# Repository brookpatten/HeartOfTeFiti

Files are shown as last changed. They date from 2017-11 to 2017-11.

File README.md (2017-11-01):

# HeartOfTeFiti
A 3d Printed Amulet with Neopixels controlled by an Arduino, Synchronized with other via NRF24 Radio.

When the button is pushed the arduino chooses a random light pattern and displays it.  While displaying it broadcasts each pixel value using the nrf24 radio to any nearby units as well.  Nearby units will receive the pixel instructions and replicate the pattern.  When the pattern ends there is a 5 second interval before another pattern can be begun (by any which participated in the previous pattern).

Components
* Shell/Cover (3d printed, models included)
* Arduino Pro Mini 3.3v
* NRF24001+ Transciever
* 5x Addressable LED
* 2x 10uf Capacitors (Optional but recommended)
* 2x 470 ohm resistors (Optional but recommended)
* wire, Recommend 30awg solid
* momentary button switch
* 3.7v 370mah li-poly Battery
* 2x M3 x 10mm Hex Head Bolt

For Assembly
 * Solder
 * Hot Glue (Optional)
 * Necklace
 
Demo

Front

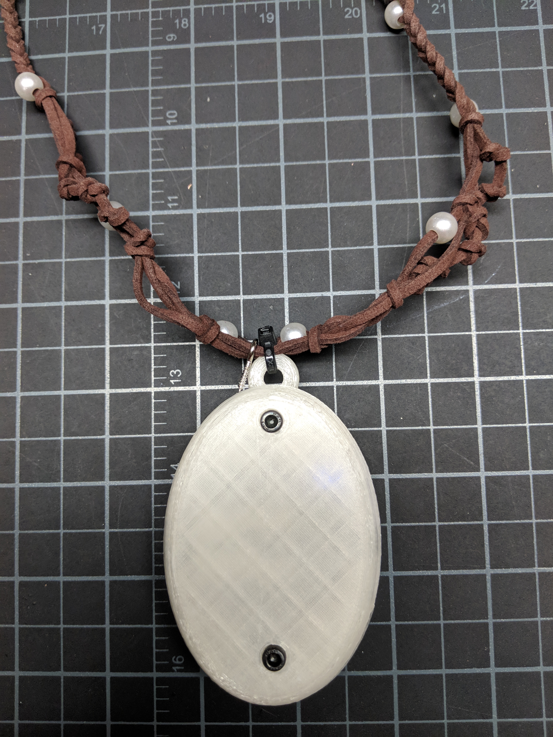
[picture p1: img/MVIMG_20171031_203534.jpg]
Back


Apart

Internals

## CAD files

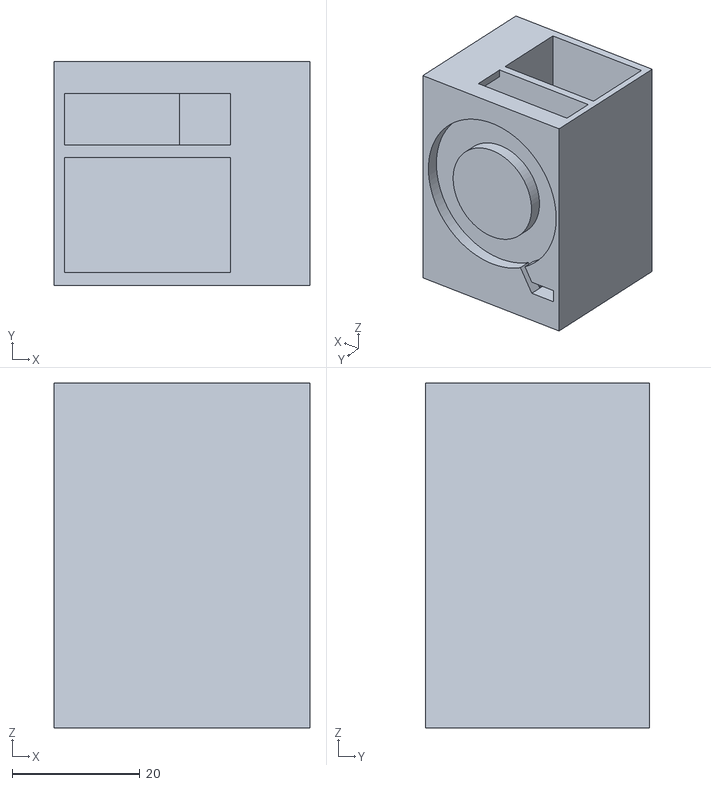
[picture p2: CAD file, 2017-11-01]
Meshes/Pumpkin-Candle.stl
40.0 x 35.0 x 54.0

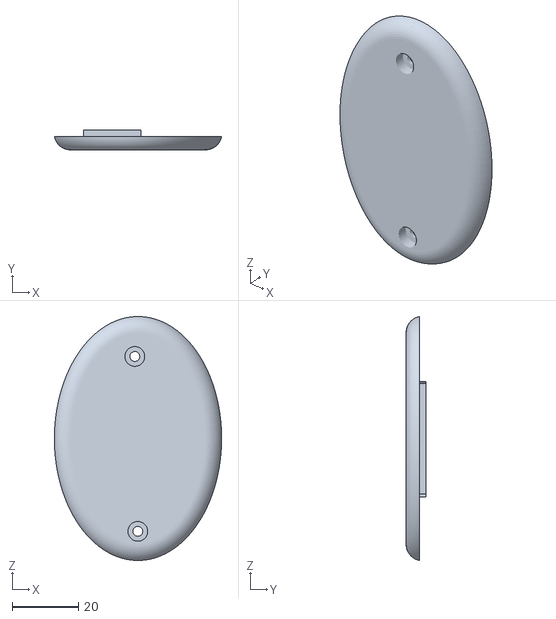
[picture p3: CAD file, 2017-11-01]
Meshes/Cover.stl
50.7 x 6.00 x 73.9

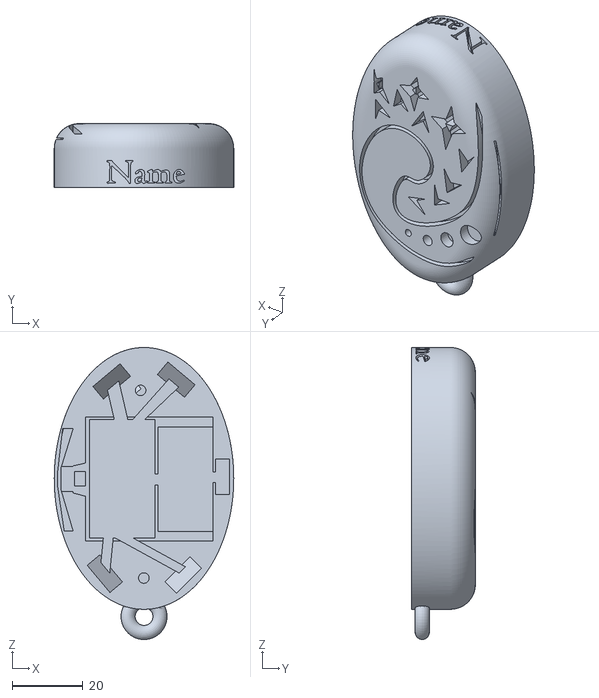
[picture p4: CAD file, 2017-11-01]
Meshes/Heart.stl
50.7 x 18.0 x 82.4

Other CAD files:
Fusion360Models/Heart.f3d
Fusion360Models/Pumpkin-Candle.f3d

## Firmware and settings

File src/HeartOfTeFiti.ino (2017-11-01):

#include <Adafruit_NeoPixel.h>
#include <SPI.h>
#include "RF24.h"
#include <printf.h>

const int pixelCount = 5;
// Parameter 1 = number of pixels in strip
// Parameter 2 = pin number (most are valid)
// Parameter 3 = pixel type flags, add together as needed:
//   NEO_KHZ800  800 KHz bitstream (most NeoPixel products w/WS2812 LEDs)
//   NEO_KHZ400  400 KHz (classic 'v1' (not v2) FLORA pixels, WS2811 drivers)
//   NEO_GRB     Pixels are wired for GRB bitstream (most NeoPixel products)
//   NEO_RGB     Pixels are wired for RGB bitstream (v1 FLORA pixels, not v2)
Adafruit_NeoPixel strip = Adafruit_NeoPixel(pixelCount, pixelCount, NEO_GRB + NEO_KHZ800);

//nrf24 radio
RF24 radio(10, 9);
byte addresses[][6] = {"1Node", "2Node"};

//millis of timestamp of last data received
volatile unsigned long lastReceive = 0;
//millis of timestamp of last data sent
volatile unsigned long lastSend = 0;
//default delay used in patterns
const int defaultDelay = 10;
const unsigned long idleTimeout = 5000;

volatile unsigned long dividerTicks = 0;
volatile unsigned long idleTicks = 0;

//this setting puts it in "pumpkin mode" so that a special version of the device 
//can be used as the light for a jackolantern and will react to the amulets too
const bool isPumpkin = false;

//structure for sending pixel commands over radio
typedef struct {
  byte index;
  byte r;
  byte g;
  byte b;
  bool show;
}
pixel;

//structure for buffering rgb combos for patterns
typedef struct {
  byte r;
  byte g;
  byte b;
}
rgb;

void setup() {
  //Serial.begin(9600);

  //pixel setup
  strip.begin();
  strip.setBrightness(64);
  strip.show(); // Initialize all pixels to 'off'

  //setup the button
  pinMode(3, INPUT);
  attachInterrupt(digitalPinToInterrupt(3), button, RISING);

  //radio setup
  radio.begin();
  radio.setDataRate(RF24_250KBPS);
  radio.setPALevel(RF24_PA_LOW);
  radio.openWritingPipe(addresses[0]);
  radio.openReadingPipe(1, addresses[0]);
  radio.setAutoAck( false ) ;
  radio.startListening();

  int channel = radio.getChannel();
  //Serial.print("Channel ");
  //Serial.println(channel);
  //printf_begin();
  //radio.printDetails();

  //if it's a pumpking show yellow
  if(isPumpkin){
    for(int i=0;i<pixelCount;i++){
      strip.setPixelColor(i, 255, 255, 0);
    }
    strip.show();
  }

  //Serial.println("Setup Complete");
  //Serial.flush();
}

//invoked when the button is pushed
void button() {
  unsigned long now = millis();

  //don't let the user interrupt a pattern in process
  if ((lastReceive == 0 || now - lastReceive > idleTimeout)
      && (lastSend == 0 || now - lastSend > idleTimeout))
  {
    randomPattern();
  }

  //if it's a pumpkin return to yello after the pattern
  if(isPumpkin){
    for(int i=0;i<pixelCount;i++){
      strip.setPixelColor(i, 255, 255, 0);
    }
    strip.show();
  }
}

//convenience method to set local and remote pixels to the same values
void setLocalAndRemotePixelColor(byte index, byte r, byte g, byte b, bool show) {
  strip.setPixelColor(index, r, g, b);
  setRemotePixelColor(index, r, g, b, show);
  if (show) {
    strip.show();
  }
}

//call at beginning of every pattern
void startPattern() {
  radio.stopListening();
  idleTicks = 0;
  dividerTicks = 0;
}

//call at end of every pattern
void endPattern() {
  clearPixels();
  idleTicks = 1;
  dividerTicks = 1;
  radio.startListening();
}

void clearPixels() {
  for (int p = 0; p < pixelCount; p++) {
    setLocalAndRemotePixelColor(p, 0, 0, 0, p == pixelCount - 1);
  }
}

//sends a pixel value to be set on listening devices
void setRemotePixelColor(byte index, byte r, byte g, byte b, bool show) {
  pixel p;
  p.index = index;
  p.r = r;
  p.g = g;
  p.b = b;
  p.show = show;

  radio.write( &p, sizeof(pixel) );

  lastSend = millis();
}

void loop() {
  if ( radio.available()) {
    pixel p;

    while (radio.available()) {
      radio.read( &p, sizeof(pixel) );
      lastReceive = millis();

      //it's possible the sender has more pixels than we do, make sure we're showing it somewhere
      strip.setPixelColor(p.index % pixelCount, p.r, p.g, p.b);
      
      if (p.show) {
        strip.show();
      }
      //reset the idle counter so that the idle pattern syncs up when this pattern is done
      idleTicks = 1;
      dividerTicks = 1;

      //if it's a pumpkin then return to yellow
      if(isPumpkin){
        if(p.r==0 && p.g==0 && p.b==0 && p.show){
          for(int i=0;i<pixelCount;i++){
            strip.setPixelColor(i, 255, 255, 0);
          }
          strip.show();
        }
      }
    }
  }
  //TODO: get this working.  Right now it seems to be interferring with the radio receive working right
  //else
  //{ 
    //if no radio
    //unsigned long now = millis();
    //if ((lastReceive == 0 || (now - lastReceive > 0 && now - lastReceive > idleTimeout))
    //    && (lastSend == 0 || (now - lastSend > 0 && now - lastSend > idleTimeout)))
    //{
      //idlePattern();
    //}
    //else
    //{
      //clearPixels();
    //}
  //}
}


//patterns

void randomPattern() {
  byte m = random(4);

  if (m == 0) {
    randomSolidPulsate();
  }
  if (m == 1) {
    transitionRotateRandomColorFade(3, 50);
  }
  else if (m == 2) {
    insanity(50);
  }
  else if (m == 3) {
    marble(10, random(255), random(255), random(255));
  }
}

void idlePattern() {

  dividerTicks++;

  if (dividerTicks >= 50) {
    idleTicks++;
    dividerTicks = 0;
  }

  unsigned int ticks = idleTicks % 510;

  for (int i = 0; i < pixelCount; i++) {
    unsigned int offset = (i * (255 / pixelCount));
    unsigned int pixelTicks = (ticks + offset) % 510;

    if (pixelTicks > 255) {
      pixelTicks = pixelTicks - 255;
      pixelTicks = 255 - pixelTicks;
    }

    if (((idleTicks + offset) / 510) % pixelCount == i) {
      strip.setPixelColor(i, 0, pixelTicks, 0);
    }
    else {
      strip.setPixelColor(i, 0, 0, pixelTicks);
    }
  }
  strip.show();

}

void insanity(int n) {
  startPattern();
  for (int i = 0; i < n; i++) {
    for (int p = 0; p < pixelCount; p++) {
      setLocalAndRemotePixelColor(p, random(255), random(255), random(255), p == pixelCount - 1);
      delay(20);
    }
  }
  endPattern();
}

void marble(int n, byte r, byte g, byte b) {
  startPattern();
  //iterations
  for (int i = 0; i < n; i++) {
    //positions in a full iteration
    for (int p = 0; p < pixelCount; p++) {
      //leds in current position
      for (int p2 = 0; p2 < pixelCount; p2++) {
        setLocalAndRemotePixelColor(p2, p2 == p ? r : 0, p2 == p ? g : 0, p2 == p ? b : 0, p2 == pixelCount - 1);
      }
      delay(100);
    }
  }
  endPattern();
}

void transitionRotateColorFade(int n, int step, byte r, byte g, byte b) {

  rgb colors[pixelCount];
  for (int i = 0; i < pixelCount; i++) {
    rgb a;
    a.r = r - ((r / pixelCount) * i);
    a.g = g - ((g / pixelCount) * i);
    a.b = b - ((b / pixelCount) * i);

    colors[i] = a;
  }

  transitionRotateColors(n, step, colors);
}

void transitionRotateRandomColorFade(int n, int step) {

  rgb colors[pixelCount];
  for (int i = 0; i < pixelCount; i++) {
    rgb a;
    a.r = random(255);
    a.g = random(255);
    a.b = random(255);

    colors[i] = a;
  }

  transitionRotateColors(n, step, colors);
}

void transitionRotateColors(int n, int step, rgb colors[]) {
  startPattern();

  //iterations
  for (int y = 0; y < n; y++) {
    //position in a complete iteration
    for (int z = 0; z < pixelCount; z++) {
      //fade to next color in steps
      for (int x = 0; x < step; x++) {
        //each led in a single step
        for (int i = 0; i < pixelCount; i++) {

          rgb current = colors[(i + z) % pixelCount];
          rgb next = colors[(i + z + 1) % pixelCount];

          setLocalAndRemotePixelColor(i
                                      , current.r + (((next.r - current.r) / step) * x)
                                      , current.g + (((next.g - current.g) / step) * x)
                                      , current.b + (((next.b - current.b) / step) * x)
                                      , i == pixelCount - 1);

        }
        delay(defaultDelay);
      }
    }
  }
  endPattern();
}

void randomSolidPulsate() {
  pulsateN(5, 50, random(255), random(255), random(255));
}

void pulsateN(int n, int step, byte r, byte g, byte b) {
  startPattern();
  for (int x = 0; x < n; x++) {
    pulsateOne(r, g, b, step);
  }
  endPattern();
}

void pulsateOne(int step, byte r, byte g, byte b) {
  for (int i = 0; i < step; i++) {
    for (int x = 0; x < pixelCount; x++) {
      setLocalAndRemotePixelColor(x, r - ((r / step)*i), g - ((g / step)*i), b - ((b / step)*i), x == pixelCount - 1);
    }
    delay(defaultDelay);
  }
  for (int i = step; i > 0; i--) {
    for (int x = 0; x < pixelCount; x++) {
      setLocalAndRemotePixelColor(x, r - ((r / step)*i), g - ((g / step)*i), b - ((b / step)*i), x == pixelCount - 1);
    }
    delay(defaultDelay);
  }
}

void randomSolid() {
  byte r = random(255);
  byte g = random(255);
  byte b = random(255);
  solid(r, g, b);
}

void solid(byte r, byte g, byte b) {
  startPattern();
  for (int x = 0; x < pixelCount; x++) {
    setLocalAndRemotePixelColor(x, r, g, b, x == pixelCount - 1);
  }
  endPattern();
}
